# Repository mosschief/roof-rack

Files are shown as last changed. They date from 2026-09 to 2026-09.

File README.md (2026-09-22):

# 2x4 lumber rack for Yakima CoreBar crossbars

A printable TPU bracket that clamps two 2x4s across a pair of Yakima CoreBar
crossbars, turning them into a flat utility rack you can strap lumber,
ladders, pipe or a canoe to — and screw accessories into, because the top
surface is just wood.

Everything that carries load is hardware-store steel. The printed parts are
the interface between the bar's teardrop section and the flat face of the
board.

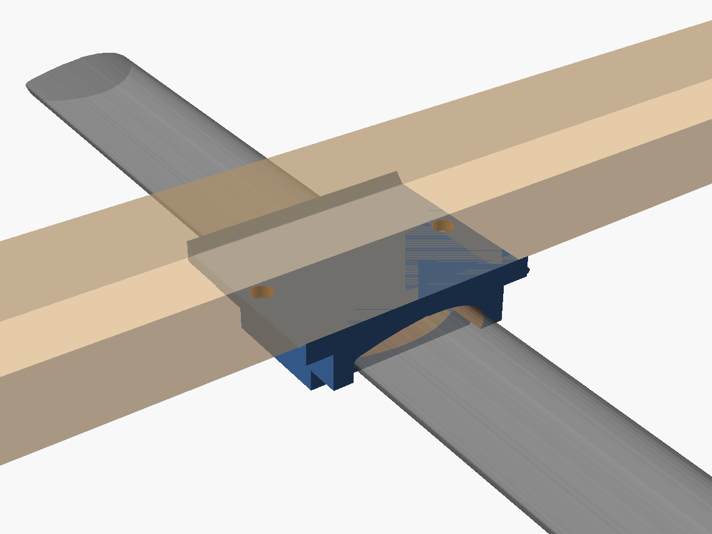
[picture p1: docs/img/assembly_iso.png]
Saddle, bar and board


## How it works

Each place a 2x4 crosses a crossbar gets one bracket, so a rack takes four.

A 3/8" square-bend U-bolt passes under the crossbar, up either side of it,
through the printed **saddle**, and through two holes drilled in the 2x4.
Washers and lock nuts on top pull the whole stack together. The steel takes
all of the tension; nothing depends on the plastic holding a load.

The printed parts do four jobs that steel alone does badly:

- The **saddle** matches the bar's rounded teardrop crown to the flat
  underside of the board, so the board sits on a full-width bearing surface
  instead of rocking on a line of contact.
- The **pad** goes under the bar, inside the bend of the U-bolt, so bare
  steel never touches the bar's vinyl coating.
- Both spread the clamp load over several square inches of bar, which is what
  keeps a hollow steel bar from being dented by a 3/8" bolt.
- TPU damps vibration. Vibration is what backs nuts off on a roof.

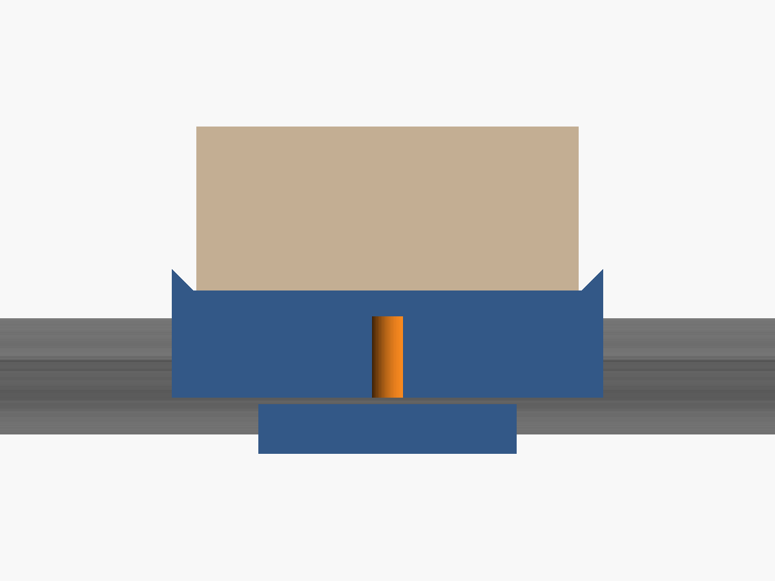
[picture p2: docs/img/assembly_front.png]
Front view


## Bill of materials

### Hardware, per bracket (you need four)

| Qty | Part | Notes |
| --- | --- | --- |
| 1 | 3/8" **square-bend U-bolt** — see "Choosing a U-bolt" below | Leg length and thread length both matter, and the obvious 7" part does not work. |
| 2 | 3/8"-16 **nylon-insert lock nut**, zinc | Use these instead of the plain nuts in the U-bolt bag. Plain nuts on a roof rack will loosen. |
| 2 | 3/8" **flat washer** | Or one 3" square U-bolt plate, sold beside the U-bolts, which spreads the load better. |
| 1 | Printed **saddle** | |
| 1 | Printed **pad** | |

### For the rack

| Qty | Part | Notes |
| --- | --- | --- |
| 2 | 2x4, 8 ft | Kiln-dried SPF is fine and cheap. Cedar is lighter and will not rot. Pick the two straightest boards on the pile and sight down them. |
| — | Exterior paint or spar urethane | Seal all six faces, including the drilled holes, or the boards will swell and check. |
| 2+ | Cam or ratchet straps | The brackets hold the rack down. Straps hold the load down. These are not the same job. |

Roughly $30 of hardware and $10–16 of lumber.

### Tools

Drill with a 7/16" bit, 9/16" wrench or socket, hacksaw and file for trimming
the U-bolt legs, tape measure, and calipers if you have them.

## Printing

| U-bolt | Saddle | Pad | Gauge | Set of four |
| --- | --- | --- | --- | --- |
| 3" opening | 106 x 100 x 30 mm, ~85 g | 75 x 60 x 12 mm, ~29 g | ~8 g | ~460 g |
| 3-1/4" opening | 113 x 100 x 30 mm, ~98 g | 81 x 60 x 12 mm, ~32 g | ~10 g | ~530 g |

About half a spool, and a long weekend of printing. TPU does not print fast.

- **Material:** TPU 95A works. 98A or 60D is better here — stiffer, and it
  creeps less under sustained clamp load.
- **Layers:** 0.2 mm, 0.4 mm nozzle.
- **Walls:** 5 perimeters. The walls do most of the work in this part.
- **Infill:** 50% gyroid.
- **Top/bottom:** 6 layers.
- **Speed:** 20–25 mm/s. Direct drive strongly preferred.
- **Supports:** none needed.

**Orientation.** Stand the saddle on end, with the bar pocket running
vertically, and use a brim. In that orientation the whole part is a vertical
extrusion and nothing overhangs — the locating lips are ramped at 45° on
purpose. The two U-bolt holes end up horizontal and may sag slightly; open
them with the 7/16" bit if a leg will not pass.

If you would rather print flat, set `lip_h = 0` and lay the part top-face-down
on the bed. You lose the lips that hold the board square while you tighten,
but the print is trivial. The U-bolts locate the board either way.

## The bar section

The pocket is traced from Yakima's own cross-section drawing, not guessed.
The drawing labels the section **70.7 mm wide by 27.0 mm tall** — about
2.78" x 1.06", which settles the 2.75" versus 3" question in favour of the
smaller one.

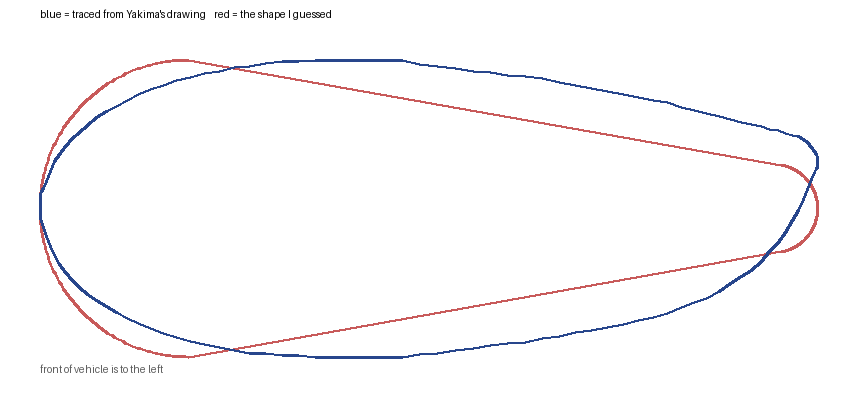
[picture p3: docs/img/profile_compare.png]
Traced section against the original guess


The shape matters more than those two numbers. The first version of this
model built the section as a teardrop hulled from two circles, with the nose
a half-round as tall as the bar. That reaches full thickness within the first
quarter of the chord and then tapers away in a straight line. The real
section keeps thickening to **36% of the chord** and stays fat much further
back, so the bar fouled the roof of the pocket through its whole middle — it
simply would not go on, however much clearance was added.

The drawing's own pixels are 70.7 x 29.3 mm rather than 70.7 x 27.0, so it is
not quite to scale. The labelled figures are what Yakima states, so each axis
was scaled to them and the outline kept its shape.

`cad/corebar_profile.scad` holds the traced polygon. `bar_w` and `bar_h`
scale it if your bar measures differently; `bar_measured = false` falls back
to the old two-circle guess.

## Check the fit before you print four

The saddle drops straight down onto the bar and snaps over a small lip at the
leading edge. It does not wrap under the trailing edge:

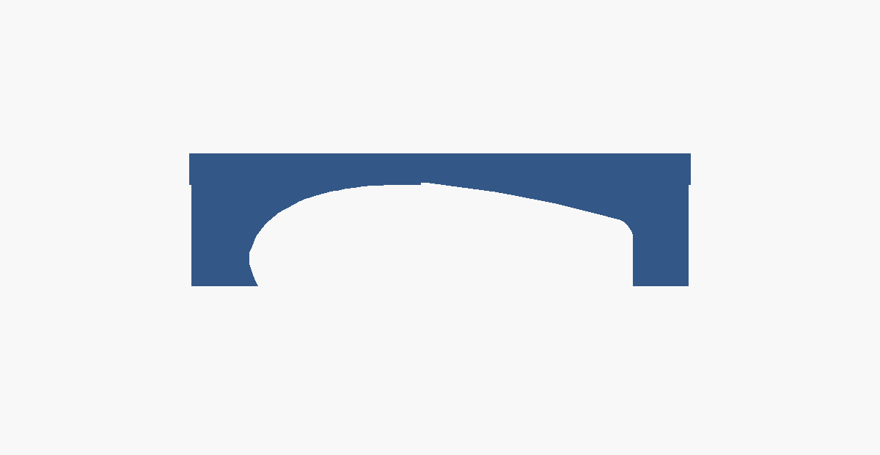
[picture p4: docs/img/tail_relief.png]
Section through the pocket


A flat-bottomed skirt cannot do this on the real section, because the
trailing edge curls up to 3.7 mm *above* the centreline — the skirt would
close underneath it, and the saddle could then only go on by hooking that tip
under the bar and rotating the nose over. So the relief follows the bar's own
underside aft of its thickest point.

**Print a gauge first.** `stl/fit-gauges/` holds the 12 mm test slice at
three clearances, notched once, twice and three times so you can tell them
apart off the bed.

| Gauge | `bar_fit` | Clearance per side |
| --- | --- | --- |
| 1 notch | 0.6 | 0.30 mm |
| 2 notch | 1.0 | 0.50 mm |
| 3 notch | 1.6 | 0.80 mm |

Keep the loosest one that has no rock in it, set `bar_fit` to that number and
render the real parts. On Sean's bar the 1-notch gauge (0.3 mm per side) fit
best, and that is now the default.

## Choosing a U-bolt

Three numbers matter, and the third is the one that catches people.

1. **Inside opening** — must clear the bar with a little room for the skirt
   walls. 3-1/4" suits either published bar section. 3" only works if the bar
   really is 2.75" wide.
2. **Leg length** — at least **3-1/2"**, measured from the inside of the bend
   to the tip. Below that the nut has nothing to bite.
3. **Thread length** — the nut has to reach *down* to the top of the stack,
   which sits **3.1" above the inside of the bend**. So the thread has to have
   started by then:

   > thread length ≥ leg length − 3.1"

A 7" leg therefore needs nearly 4" of thread. Square U-bolts that long are
typically threaded only 1-1/2" from each tip, so the nut runs out of thread in
mid-air above the board and never touches it. Long legs are not the safe
choice here; they are the failure.

| Leg | Thread needed | Verdict |
| --- | --- | --- |
| 3-1/2" | 3/8" | tight but works |
| 4" | 7/8" | comfortable, the sweet spot |
| 4-1/2" | 1-3/8" | fine |
| 5" | 1-7/8" | check the listing carefully |
| 7" | 3-7/8" | will not work unless fully threaded |

Fully threaded legs sidestep the whole issue.

Set `ubolt_leg` and `ubolt_thread` in the `.scad` to whatever you are holding
and it will refuse to render, with the reason, if the nut cannot reach.

## If your U-bolt is a different width

Set `ubolt_inside` to the opening you have, in millimetres, and re-render.
Everything that depends on it follows: the hole pitch, the saddle's footprint,
and — the part that matters — the thickness of the skirt walls.

That last one is not cosmetic. A 3-1/4" U-bolt on a 2.75" bar leaves about
1/4" of free space on each side of the bar, so a saddle built for a 3" U-bolt
would let the bar slide almost half an inch fore-and-aft inside the bend
before anything stopped it. The model closes that gap by growing the skirt
walls out to meet the legs, and the leg holes, which are cut full depth,
scallop a cradle into the outside of each wall so the leg is held against the
bar rather than floating beside it.

Leg length is not sensitive. The stack — pad, bar, saddle, 2x4, washer and nut
— comes to about 3-1/2", so 7" legs leave plenty over on any of these.

## Where the numbers came from

- CoreBar section, 70.7 x 27.0 mm, traced from the drawing in
  [Yakima's support article on CoreBar dimensions](https://yakimasupport.zendesk.com/hc/en-us/articles/236010788-CoreBar-Bar-Dimensions).
  The retailer listings say 2.75" x 1.10", which is close on width and 1 mm
  out on height.
- U-bolt, 3/8" x 3" opening x 7" legs, A307 steel, nuts included —
  [Everbilt 810226 at The Home Depot](https://www.homedepot.com/p/Everbilt-3-8-in-x-3-in-x-7-in-Zinc-Plated-Square-U-Bolt-810226/204775849).
- 2x4 actual dimensions, 1.5" x 3.5" — standard dressed lumber.

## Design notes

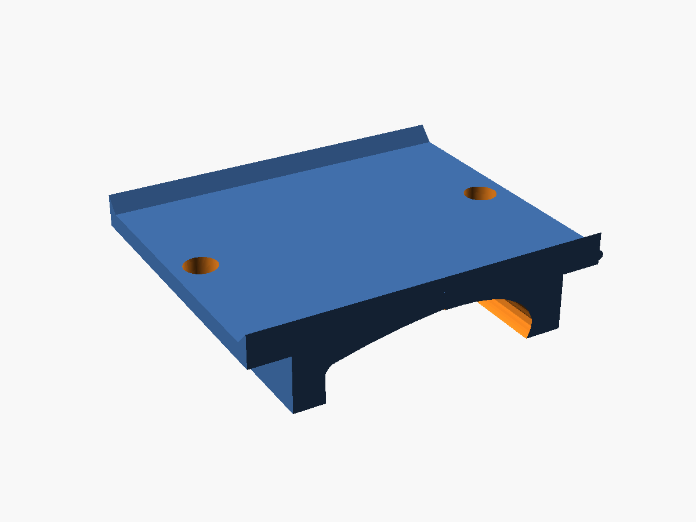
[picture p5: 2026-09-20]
docs/img/saddle.png

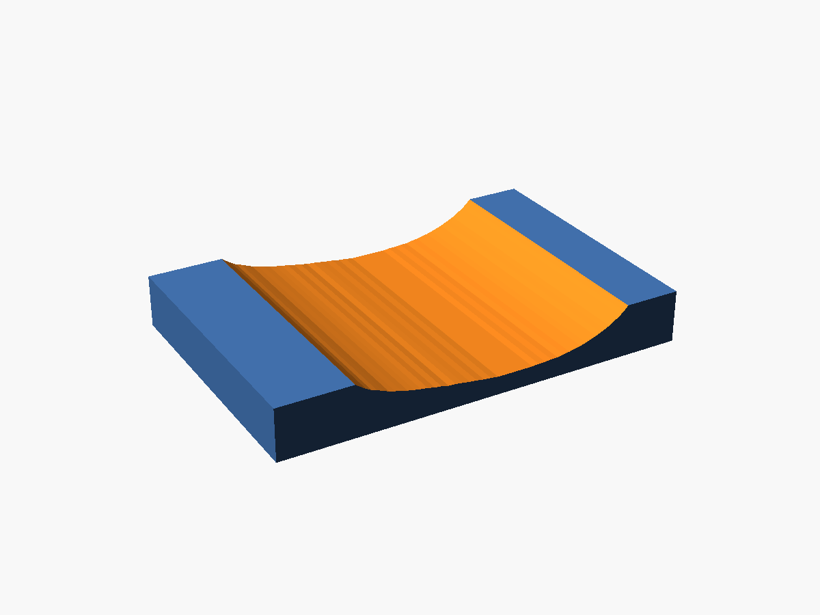
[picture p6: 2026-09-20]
docs/img/pad.png

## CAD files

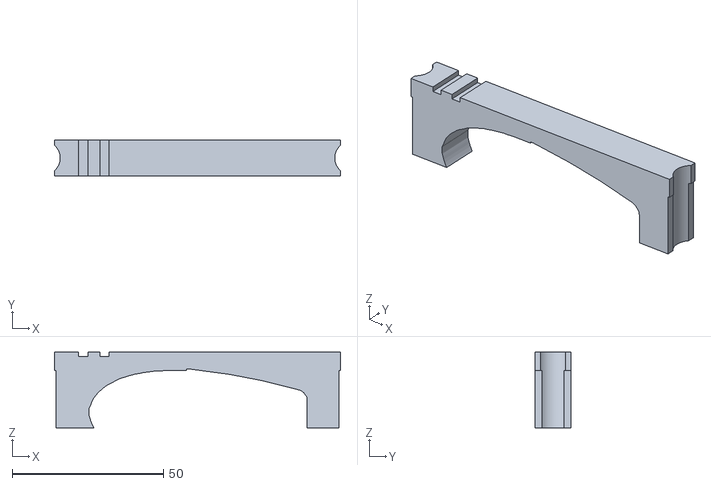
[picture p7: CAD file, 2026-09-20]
stl/fit-gauges/2-notch_1.0mm-total.stl
94.5 x 12.0 x 25.0

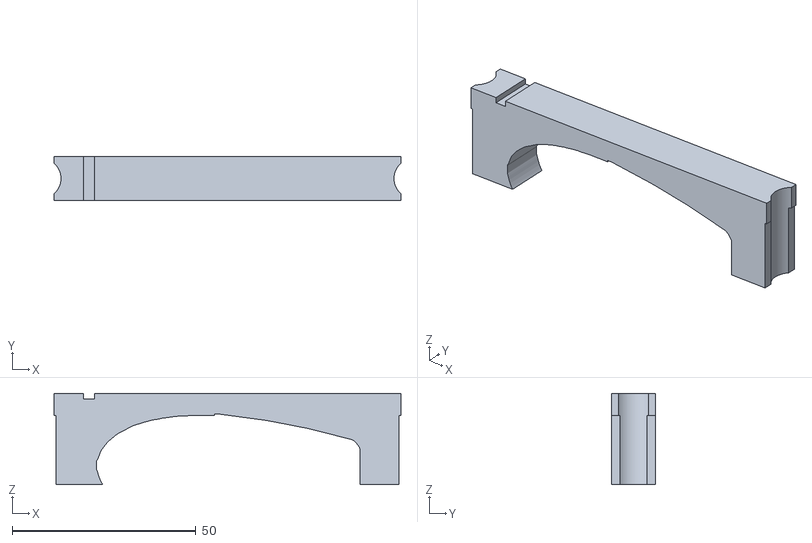
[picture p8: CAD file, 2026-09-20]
stl/fit-gauges/1-notch_0.6mm-total.stl
94.5 x 12.0 x 24.8

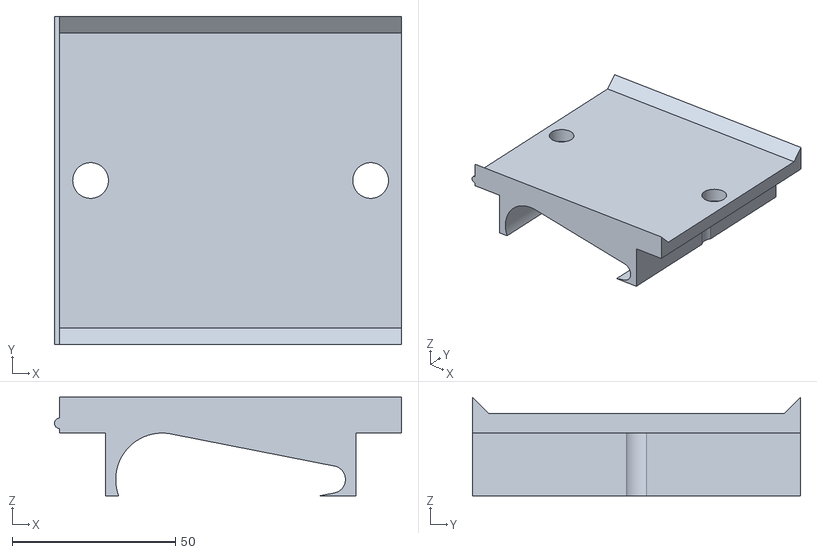
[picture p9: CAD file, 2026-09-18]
stl/corebar_2x4_saddle.stl
106.2 x 100.4 x 30.2

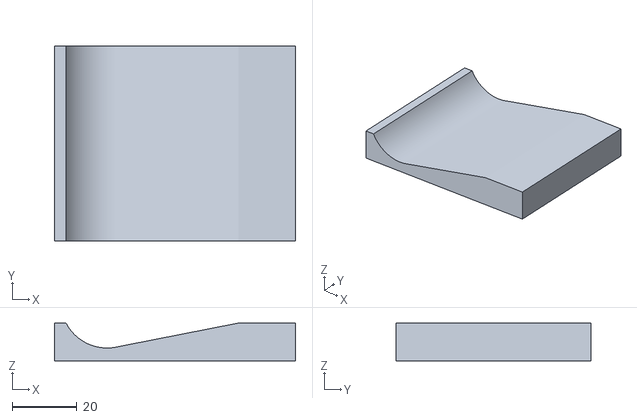
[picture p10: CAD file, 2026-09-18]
stl/corebar_2x4_pad.stl
74.3 x 60.0 x 11.7

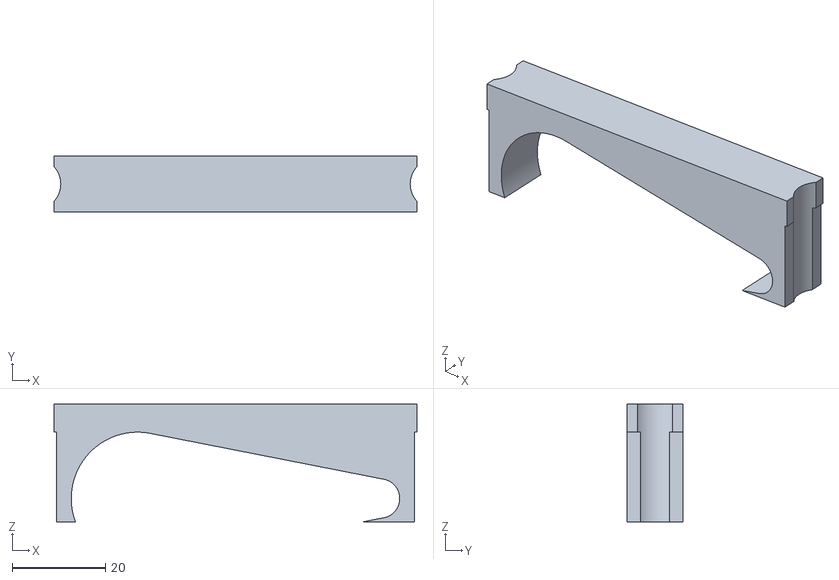
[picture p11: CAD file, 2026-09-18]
stl/corebar_2x4_gauge.stl
77.7 x 12.0 x 25.2

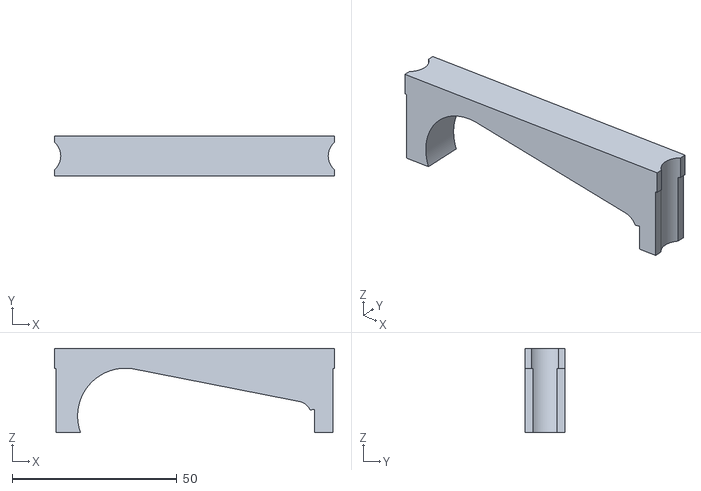
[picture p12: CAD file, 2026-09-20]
stl/fit-gauges/gauge_fit-1.0mm.stl
85.0 x 12.0 x 25.5

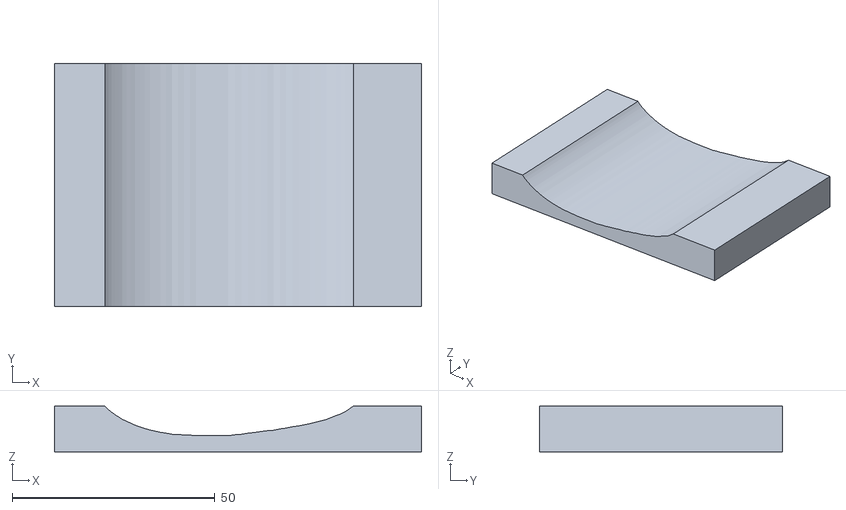
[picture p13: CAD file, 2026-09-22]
stl/ubolt-3.625in/pad.stl
90.6 x 60.0 x 11.3

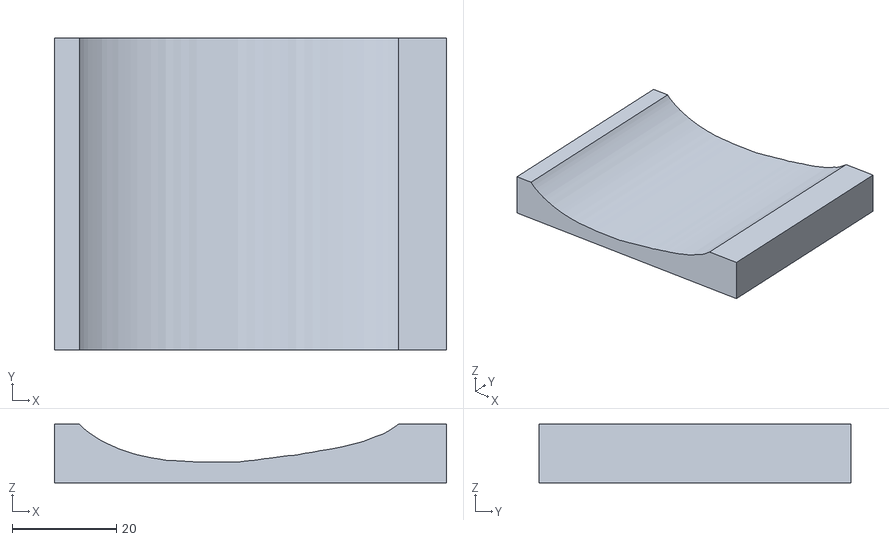
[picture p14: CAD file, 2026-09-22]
stl/ubolt-3in/pad.stl
75.3 x 60.0 x 11.3

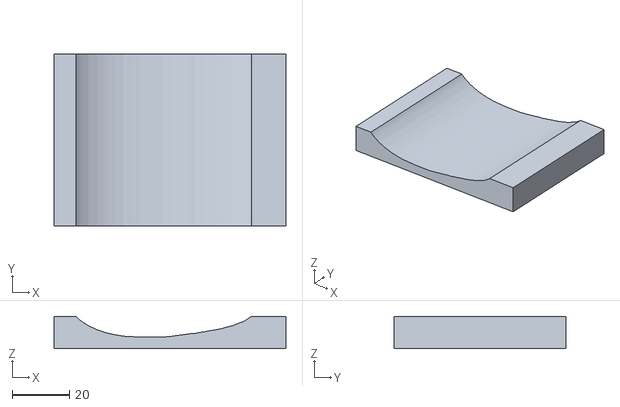
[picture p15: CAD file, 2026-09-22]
stl/ubolt-3.25in/pad.stl
81.0 x 60.0 x 11.3

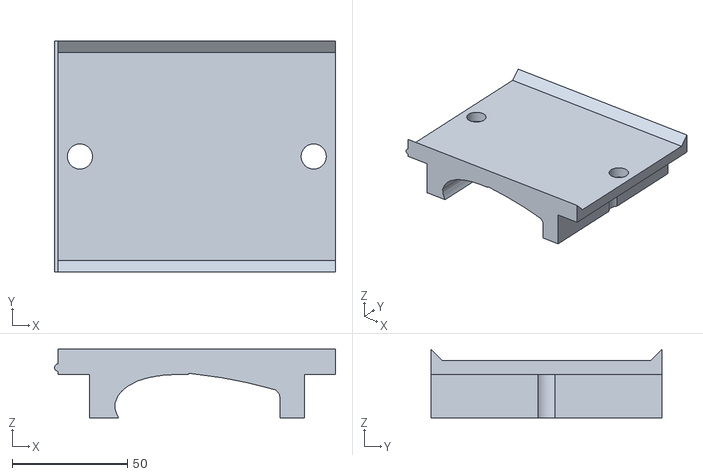
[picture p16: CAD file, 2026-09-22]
stl/ubolt-3.625in/saddle.stl
122.1 x 100.4 x 29.8

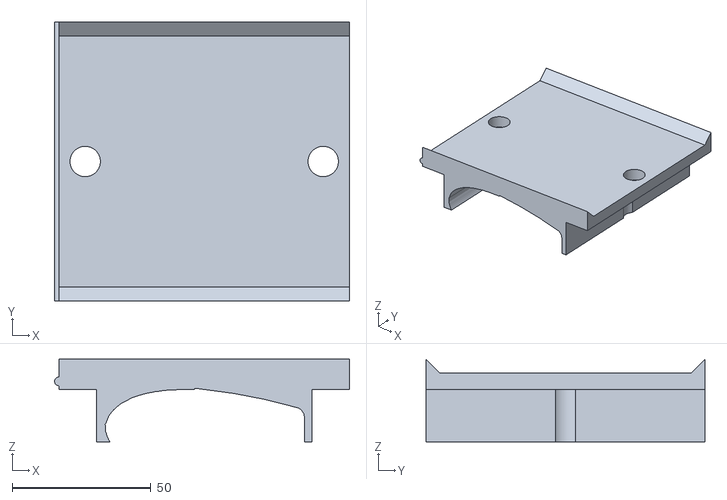
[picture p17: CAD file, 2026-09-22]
stl/ubolt-3in/saddle.stl
106.2 x 100.4 x 29.8

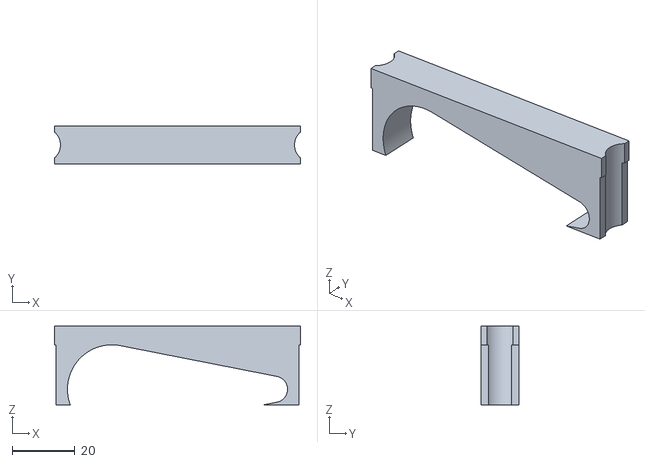
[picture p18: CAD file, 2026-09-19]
stl/ubolt-3in/gauge.stl
78.6 x 12.0 x 25.2

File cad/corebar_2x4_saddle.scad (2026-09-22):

// ---------------------------------------------------------------------------
// corebar_2x4_saddle.scad
//
// Flexible (TPU) parts that clamp a 2x4 laid flat on top of a Yakima CoreBar
// crossbar, using a 3/8" square-bend U-bolt from any hardware store.
//
// The printed parts do not carry the load.  The U-bolt passes under the bar,
// up either side of it, through the saddle and through two holes drilled in
// the 2x4; the steel takes all the tension.  The TPU matches the bar's
// teardrop section to the flat underside of the board, spreads the clamp load
// so the bar is not dented, keeps steel off the bar's coating, grips, and
// damps the vibration that otherwise backs nuts off.
//
// Two parts:
//   saddle - sits on top of the bar, under the board
//   pad    - sits under the bar, inside the bend of the U-bolt
//
// Four of each make a rack: two 2x4s running fore-and-aft over two crossbars.
//
// All dimensions are millimetres.  Print gauge() first and try it on the real
// bar before committing to four full sets.
// ---------------------------------------------------------------------------

/* [What to render] */
part = "saddle";  // [saddle, pad, gauge, assembly]

include <corebar_profile.scad>

/* [Crossbar section] */
// The section is now traced from Yakima's own cross-section drawing rather
// than guessed -- see corebar_profile.scad.  Set bar_measured = false to fall
// back to the old two-circle teardrop.
bar_measured = true;
// Two published sections disagree, and they differ by a quarter inch in
// width, which is more than the whole design margin.  MEASURE YOUR BAR.
//   2.75 x 1.10 in = 69.9 x 28.0  (Yakima's product listing, and retailers)
//   3.00 x 1.00 in = 76.2 x 25.4  (Yakima's own support article)
// On a 3.00 in bar a 3 in U-bolt cannot close around it at all; a 3-1/4 in
// one still works.  stl/fit-gauges/ has a test slice for each section.
bar_w        = 70.70;  // fore-and-aft, from the drawing
bar_h        = 27.00;  // vertical at the thickest point, from the drawing
bar_tail_r   = 4.0;    // radius of the thin trailing edge
bar_teardrop = true;   // false gives a symmetric obround pocket
// Most aero crossbars are flat underneath so they can sit in the tower clamp,
// with all the curve on top.  The teardrop above is symmetric top to bottom,
// which is a guess.  If the pocket's big end looks too round against the real
// bar, try this: it puts the curve on top and a flat underside.
bar_flat_bottom = false;
bar_fit      = 0.6;    // total clearance added to the pocket (0.3 per side)

/* [Lumber] */
board_w   = 88.9;  // 3.5 in, the real width of a 2x4
board_t   = 38.1;  // 1.5 in, the real thickness of a 2x4
board_fit = 1.5;   // slack for paint, swelling and saw-rough edges

/* [U-bolt] */
// A 3/8 in square-bend U-bolt.  Set ubolt_inside to the opening you actually
// bought; the skirt and pad thicken or thin themselves to suit, so the legs
// always end up cradled tight against the bar.
//   3     in opening = 76.20  (Everbilt 810226)
//   3-1/4 in opening = 82.55
rod_d        = 9.525;  // 3/8 in
ubolt_inside = 92.075; // 3-5/8 in
hole_fit     = 1.4;    // clearance on the leg holes
// Leg length alone does not tell you whether a U-bolt fits.  The nut has to
// reach DOWN to the top of the stack, so the thread must already have started
// by that height.  A long leg with a short thread cannot clamp anything: the
// nut runs out of thread in mid-air above the board.  Measure both from the
// tip of the leg.
ubolt_leg    = 101.6;  // 4 in, inside of the bend to the tip of the leg
ubolt_thread = 38.1;   // 1-1/2 in of thread, measured down from the tip
washer_t     = 3.0;    // load-spreading plate or fender washer
nut_h        = 8.4;    // 3/8-16 nut

/* [Saddle] */
floor_t = 6.0;   // TPU between the crown of the bar and the board
wall_t  = 0;     // skirt wall beside the bar; 0 = fill out to the U-bolt legs
snap    = 5.0;   // how far the skirt wraps below the bar's widest line
tail_open  = true; // leave the thin trailing edge uncovered, see tail_relief()
tail_open_x = 0;   // where the relief starts; 0 = auto, at the nose's centre
tail_clear  = 2.0; // unused with the measured section; kept for the old one
lip_h   = 5.0;   // locating lips that capture the board's width
end_pad = 4.0;   // material beyond the leg holes, fore and aft
bead_r  = 1.6;   // bead on the leading face, so FORWARD is obvious

/* [Pad] */
pad_t    = 4.0;   // TPU between the bar and the bend of the U-bolt
pad_wall = 0;     // side walls; 0 = fill out to just inside the U-bolt legs
pad_len  = 60.0;  // length along the bar
pad_gap  = 1.5;   // clearance between pad and saddle

/* [Quality] */
$fa = 2;
$fs = 0.4;

// --- derived ---------------------------------------------------------------
leg_cc   = ubolt_inside + rod_d;            // leg centre-to-centre spacing
hole_d   = rod_d + hole_fit;
cav_w    = bar_w + bar_fit;
cav_h    = bar_h + bar_fit;

// Room between the side of the bar and the inside face of a U-bolt leg.  A
// wider U-bolt leaves the bar free to slide fore-and-aft inside the bend, so
// the skirt wall grows to fill that space and the leg holes, cut full depth,
// scallop it into a cradle that holds each leg against the bar.
side_gap = (ubolt_inside - cav_w) / 2;
wall     = (wall_t > 0) ? wall_t : side_gap + 0.7;
p_wall   = (pad_wall > 0) ? pad_wall : max(2.0, side_gap - 0.75);

skirt_x  = cav_w + 2 * wall;                // fore-and-aft footprint of skirt
body_x   = leg_cc + hole_d + 2 * end_pad;   // fore-and-aft footprint of slab
y_in     = (board_w + board_fit) / 2;       // inner face of the locating lips
body_y   = 2 * (y_in + lip_h);              // length along the bar
cav_z    = -floor_t - cav_h / 2;            // centre height of the bar pocket
nose_cx  = -cav_w / 2 + cav_h / 2;          // centre of the teardrop's nose
// Start the relief just behind the thickest part of the section, so the
// skirt wraps the fat end and opens over everything aft of it.
relief_x = (tail_open_x != 0) ? tail_open_x
         : bar_measured ? -cav_w / 2 + 0.45 * cav_w
         : nose_cx;
cav_bot  = cav_z - cav_h / 2;               // lowest point of the bar
skirt_bz = cav_z - snap;                    // bottom of the saddle skirt
pad_top  = skirt_bz - pad_gap;
pad_bot  = cav_bot - pad_t;

echo(str("drill the 2x4 at this hole pitch: ", leg_cc, " mm = ",
         leg_cc / 25.4, " in"));
echo(str("clearance per side between bar and U-bolt leg: ", side_gap, " mm"));
echo(str("skirt wall: ", wall, " mm    pad wall: ", p_wall, " mm"));
echo(str("pocket: ", cav_w, " x ", cav_h, " mm, i.e. ", bar_fit / 2,
         " mm clearance per side"));
// Height of the nut's seat above the inside of the U-bolt's bend.
stack = pad_t + bar_h + floor_t + board_t + washer_t;
thread_starts = ubolt_leg - ubolt_thread;
echo(str("nut seats ", stack, " mm = ", stack / 25.4,
         " in above the inside of the bend"));
echo(str("so the thread must start by ", stack / 25.4,
         " in from the bend; yours starts at ", thread_starts / 25.4, " in"));
echo(str("minimum usable leg: ", (stack + nut_h) / 25.4, " in"));
assert(side_gap > 1.5, "U-bolt opening is too small for this bar section");
assert(wall >= 2.4, "skirt wall too thin to print; use a wider U-bolt");
assert(p_wall >= 2.0, "pad wall too thin to print");
assert(ubolt_leg >= stack + nut_h,
       "U-bolt legs are too short to reach through the stack");
assert(thread_starts <= stack,
       "U-bolt thread does not reach far enough down the leg: the nut runs out of thread before it touches the stack. Use a shorter leg or a longer thread.");
// The skirt is deliberately wider than the U-bolt opening: it only has to
// clear the legs where they actually pass, at the middle of the saddle, and
// the leg holes cut that clearance themselves.
assert(cav_w + 2 * p_wall < ubolt_inside, "pad would not fit between the legs");
assert(pad_top < skirt_bz, "pad and saddle would collide");

// --- geometry --------------------------------------------------------------

// Section of the bar in the fore-and-aft / vertical plane.  The nose (the
// thick, rounded edge) points toward -X, which is the front of the vehicle.
module cavity_2d() {
    if (bar_measured)
        offset(r = bar_fit / 2)
            scale([bar_w / corebar_nominal_w, bar_h / corebar_nominal_h])
                corebar_profile_2d();
    else
        guessed_section_2d();
}
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

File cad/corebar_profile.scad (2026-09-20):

// corebar_profile.scad -- CoreBar section, traced from Yakima's own
// cross-section drawing (CoreBar_Cross_Section__002_.png, support article
// 236010788).  The drawing labels the section 70.7 mm wide by 27.0 mm tall;
// its pixels are in that ratio horizontally but 29.3 mm tall, so each axis
// was scaled to the labelled figure and the outline kept its shape.
// Nose (blunt end) at -X, which is the front of the vehicle.
// Nominal, before clearance: 70.7 x 27.0 mm.

corebar_nominal_w = 70.70;
corebar_nominal_h = 27.00;

module corebar_profile_2d() {
    polygon(points = [
        [-35.350, 1.356], [-35.204, 1.529], [-35.021, 1.849], [-34.765, 2.493],
        [-34.438, 3.390], [-34.039, 4.281], [-33.570, 4.890], [-33.031, 5.598],
        [-32.423, 6.322], [-31.749, 6.937], [-31.008, 7.562], [-30.204, 8.236],
        [-29.336, 8.789], [-28.408, 9.257], [-27.421, 9.777], [-26.378, 10.377],
        [-25.279, 10.862], [-24.128, 11.196], [-22.927, 11.596], [-21.679, 11.918],
        [-20.386, 12.288], [-19.050, 12.465], [-17.675, 12.784], [-16.263, 12.940],
        [-14.818, 13.162], [-13.342, 13.323], [-11.838, 13.323], [-10.310, 13.466],
        [-8.760, 13.500], [-7.192, 13.500], [-5.609, 13.500], [-4.015, 13.500],
        [-2.412, 13.500], [-0.805, 13.083], [0.805, 12.880], [2.412, 12.725],
        [4.015, 12.488], [5.609, 12.324], [7.192, 12.114], [8.760, 11.964],
        [10.310, 11.784], [11.838, 11.458], [13.342, 11.222], [14.818, 10.914],
        [16.263, 10.639], [17.675, 10.345], [19.050, 10.114], [20.386, 9.785],
        [21.679, 9.598], [22.927, 9.205], [24.128, 8.908], [25.279, 8.650],
        [26.378, 8.373], [27.421, 8.112], [28.408, 7.854], [29.336, 7.638],
        [30.204, 7.447], [31.008, 7.182], [31.749, 7.047], [32.423, 6.818],
        [33.031, 6.679], [33.570, 6.574], [34.039, 6.317], [34.438, 5.986],
        [34.765, 5.524], [35.021, 5.142], [35.204, 4.896], [35.313, 4.768],
        [35.350, 3.730], [35.204, 3.636], [35.021, 3.270], [34.765, 2.641],
        [34.438, 1.757], [34.039, 0.832], [33.570, -0.173], [33.031, -1.134],
        [32.423, -2.164], [31.749, -3.105], [31.008, -3.897], [30.204, -4.849],
        [29.336, -5.615], [28.408, -6.162], [27.421, -6.860], [26.378, -7.566],
        [25.279, -8.153], [24.128, -8.539], [22.927, -9.015], [21.679, -9.523],
        [20.386, -9.867], [19.050, -10.195], [17.675, -10.555], [16.263, -10.834],
        [14.818, -11.099], [13.342, -11.299], [11.838, -11.624], [10.310, -11.821],
        [8.760, -12.165], [7.192, -12.268], [5.609, -12.473], [4.015, -12.713],
        [2.412, -12.880], [0.805, -13.146], [-0.805, -13.271], [-2.412, -13.500],
        [-4.015, -13.500], [-5.609, -13.500], [-7.192, -13.500], [-8.760, -13.500],
        [-10.310, -13.500], [-11.838, -13.355], [-13.342, -13.323], [-14.818, -13.191],
        [-16.263, -13.146], [-17.675, -12.880], [-19.050, -12.681], [-20.386, -12.385],
        [-21.679, -12.104], [-22.927, -11.740], [-24.128, -11.332], [-25.279, -10.930],
        [-26.378, -10.425], [-27.421, -9.974], [-28.408, -9.494], [-29.336, -8.906],
        [-30.204, -8.339], [-31.008, -7.785], [-31.749, -7.179], [-32.423, -6.512],
        [-33.031, -5.798], [-33.570, -5.051], [-34.039, -4.265], [-34.438, -3.445],
        [-34.765, -2.590], [-35.021, -1.731], [-35.204, -1.199], [-35.313, -0.914],
    ]);
}

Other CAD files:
stl/fit-gauges/3-notch_1.6mm-total.stl
stl/fit-gauges/gauge_fit-1.8mm.stl
stl/fit-gauges/gauge_fit-1.4mm.stl
stl/ubolt-3.25in/saddle.stl
stl/ubolt-3.25in/gauge.stl

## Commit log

2026-09-18 Add TPU saddle and pad that clamp 2x4s to Yakima CoreBar crossbars
    Parametric OpenSCAD source, rendered STLs, and a build guide for a
    four-bracket lumber rack.
    The printed parts are the interface, not the structure. A 3/8" square-bend
    U-bolt (Everbilt 810226, 3" opening) passes under the crossbar, up either
    side, through the saddle and through the 2x4; the steel takes all the
    tension. The saddle matches the bar's 2.75" x 1.10" JetFlow teardrop crown
    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
    [corebar_2x4_gauge.stl, corebar_2x4_pad.stl, corebar_2x4_saddle.scad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]
2026-09-19 Support 3-1/4 in U-bolts; derive skirt and pad walls from the opening
    A 3-1/4 in square-bend U-bolt is what is actually on the shelf in most
    stores. Its legs stand 6.1 mm clear of a 2.75 in bar, against 2.95 mm for a
    3 in one, so a saddle built for the narrower bolt left the bar free to slide
    about 0.48 in fore-and-aft inside the bend before anything stopped it.
    wall_t and pad_wall now derive from ubolt_inside by default: the skirt grows
    out to 0.7 mm past the inside face of each leg, and the leg holes, already
    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
    [corebar_2x4_saddle.scad, gauge.stl, pad.stl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]
2026-09-20 Open the skirt over the trailing edge and loosen the bar pocket
    Sean's first print would not go on. Two causes, both real.
    The skirt closed underneath the bar's thin trailing edge. Its bottom was a
    flat plane 5 mm below the bar's widest line, but the teardrop's tail sits
    well above that, so from x = 27 mm rightward the skirt wrapped under the bar
    -- leaving 0.72 mm of TPU beneath the tail, thinner than one perimeter. The
    saddle could only go on by hooking that tip under the bar and rotating the
    nose over. tail_relief() now cuts the skirt away on the tail side, rising
    from the full wrap at the nose to clear of the bar by the trailing edge. A
    solid test against the swept volume under the bar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
    [corebar_2x4_saddle.scad, gauge.stl, gauge_fit-0.6mm.stl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]
2026-09-20 Add fit gauges for both published CoreBar sections
    Sean's first print did not just bind, it would not go on, which fits a wider
    bar as well as it fits the trailing-edge wrap fixed in c4adfd0. The two
    published sections differ by a quarter inch of width and in opposite
    directions on height -- 2.75 x 1.10 in from Yakima's listing and the
    retailers, 3.00 x 1.00 in from Yakima's support article -- so no single
    clearance ladder can separate them.
    stl/fit-gauges/ now holds the test slice for each section at two clearances,
    and the README says which variables each file corresponds to.
    Checked both sections through the model. On a 3.00 in bar a 3 in U-bolt gives
    side_gap = -0.5 mm and trips the as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
    [corebar_2x4_saddle.scad, gauge_bar-2.75x1.10_fit-1.0mm.stl, gauge_bar-2.75x1.10_fit-1.6mm.stl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]
2026-09-20 Check that the U-bolt's thread reaches the nut, not just its legs
    Sean's 7 in U-bolts would not clamp: the legs were long enough but the thread
    was not, so the nut ran out of thread above the board and never reached the
    stack. Leg length was checked when the design was written; thread length was
    not, and it is the binding constraint.
    The nut seats 79.1 mm (3.11 in) above the inside of the bend -- pad, bar,
    saddle floor, 2x4 and washer. The thread therefore has to start by that
    height, i.e. thread length must be at least leg length minus 3.11 in. A 7 in
    leg needs nearly 4 in of thread; square U-bolts that long usually carry about
    1-1/2 in.
    ubolt_leg and ubolt_thread are now parameters, and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
    [corebar_2x4_saddle.scad]
2026-09-20 Default to the 3-5/8 in U-bolt; make the gauges separate size from shape
    Sean's replacement U-bolt is 3/8 in x 3-5/8 in W x 4 in L. Checked through
    the model: the nut seats 3.11 in above the bend and a 4 in leg threaded 1-1/2
    in from the tip starts at 2.5 in, so it reaches. Hole pitch becomes exactly
    4 in. The wider opening leaves 10.6 mm per side, which the skirt fills, so
    the saddle grows to 122 mm and about 115 g.
    He also reports the bar is the 2.75 in section, but that neither 2.75 in
    gauge would seat and both felt identical -- they were only 0.3 mm per side
    apart, too fine to tell by hand. The gauges are now 1, 2 and 3 mm per side,
    notched once, twice and three times so they can be tol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
    [1-notch_round_1.0mm-per-side.stl, 2-notch_round_2.0mm-per-side.stl, 3-notch_round_3.0mm-per-side.stl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]
2026-09-20 Trace the bar section from Yakima's drawing instead of guessing it
    Sean supplied the cross-section drawing from Yakima's support article, which
    until now was only readable as an image. Traced it: flood-fill the background
    from the border, take the largest blob, strip the dimension lines with an
    erode/dilate, then sample top and bottom edges on cosine spacing into a
    136-point polygon in cad/corebar_profile.scad.
    This explains every fit problem so far. The guessed section was a teardrop
    hulled from two circles with the nose a half-round as tall as the bar, so it
    reached full thickness in the first quarter of the chord and then tapered in
    a straight line. The real section keeps thickening to 3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
    [1-notch_0.6mm-total.stl, 1-notch_round_1.0mm-per-side.stl, 2-notch_1.0mm-total.stl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]
2026-09-22 Set the bar-pocket clearance to the fit Sean measured
    The 1-notch fit gauge (0.3 mm per side, bar_fit = 0.6) seated best on the
    real bar, so that is now the default. Re-rendered all three U-bolt variants;
    the tighter pocket still lets the bar drop straight in, leaving a 1.3 mm nose
    lip and nothing under the rest of the bar.
    Claude-Session: https://claude.ai/code/session_012yjkhoCpZjNSaL41mUJAho
    [corebar_2x4_saddle.scad, pad.stl, saddle.stl]
2026-10-10 Add a true-scale printable drilling template for the 2x4 and plate
    Claude-Session: https://claude.ai/code/session_01PbFwXZF354RZPApQqtT3KQ
2026-10-10 Add a 3D-printable drill guide for the 2x4
    Paper printers, phones especially, can scale the PDF template; a printed
    guide holds the U-bolt pitch exactly.
    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
2026-10-10 Replace the 2x4 drill guide with one for the steel plate
    The saddle already marks the board; the flat-bar plate is the piece that
    needs a guide. Pilot holes at the U-bolt pitch, located by an end stop.
    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
2026-10-11 Size the plate guide for 1-1/4 in flat bar
    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
